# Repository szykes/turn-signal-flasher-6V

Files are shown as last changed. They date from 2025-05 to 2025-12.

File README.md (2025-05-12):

# Turn signal flasher on 6 V for MZ TS 125

This is a template project for old AT90*, ATmega*, and ATtiny* projects. It uses a simple testing and mocking framework and relies on own `avr-libc` version.

## Building firmware
```
cmake -S . -B cmake
```

```
cmake --build cmake --target app
```

## Building and running test
```
cmake -DTEST=True -S . -B cmake-test
```

```
cmake --build cmake-test --target app-test
```

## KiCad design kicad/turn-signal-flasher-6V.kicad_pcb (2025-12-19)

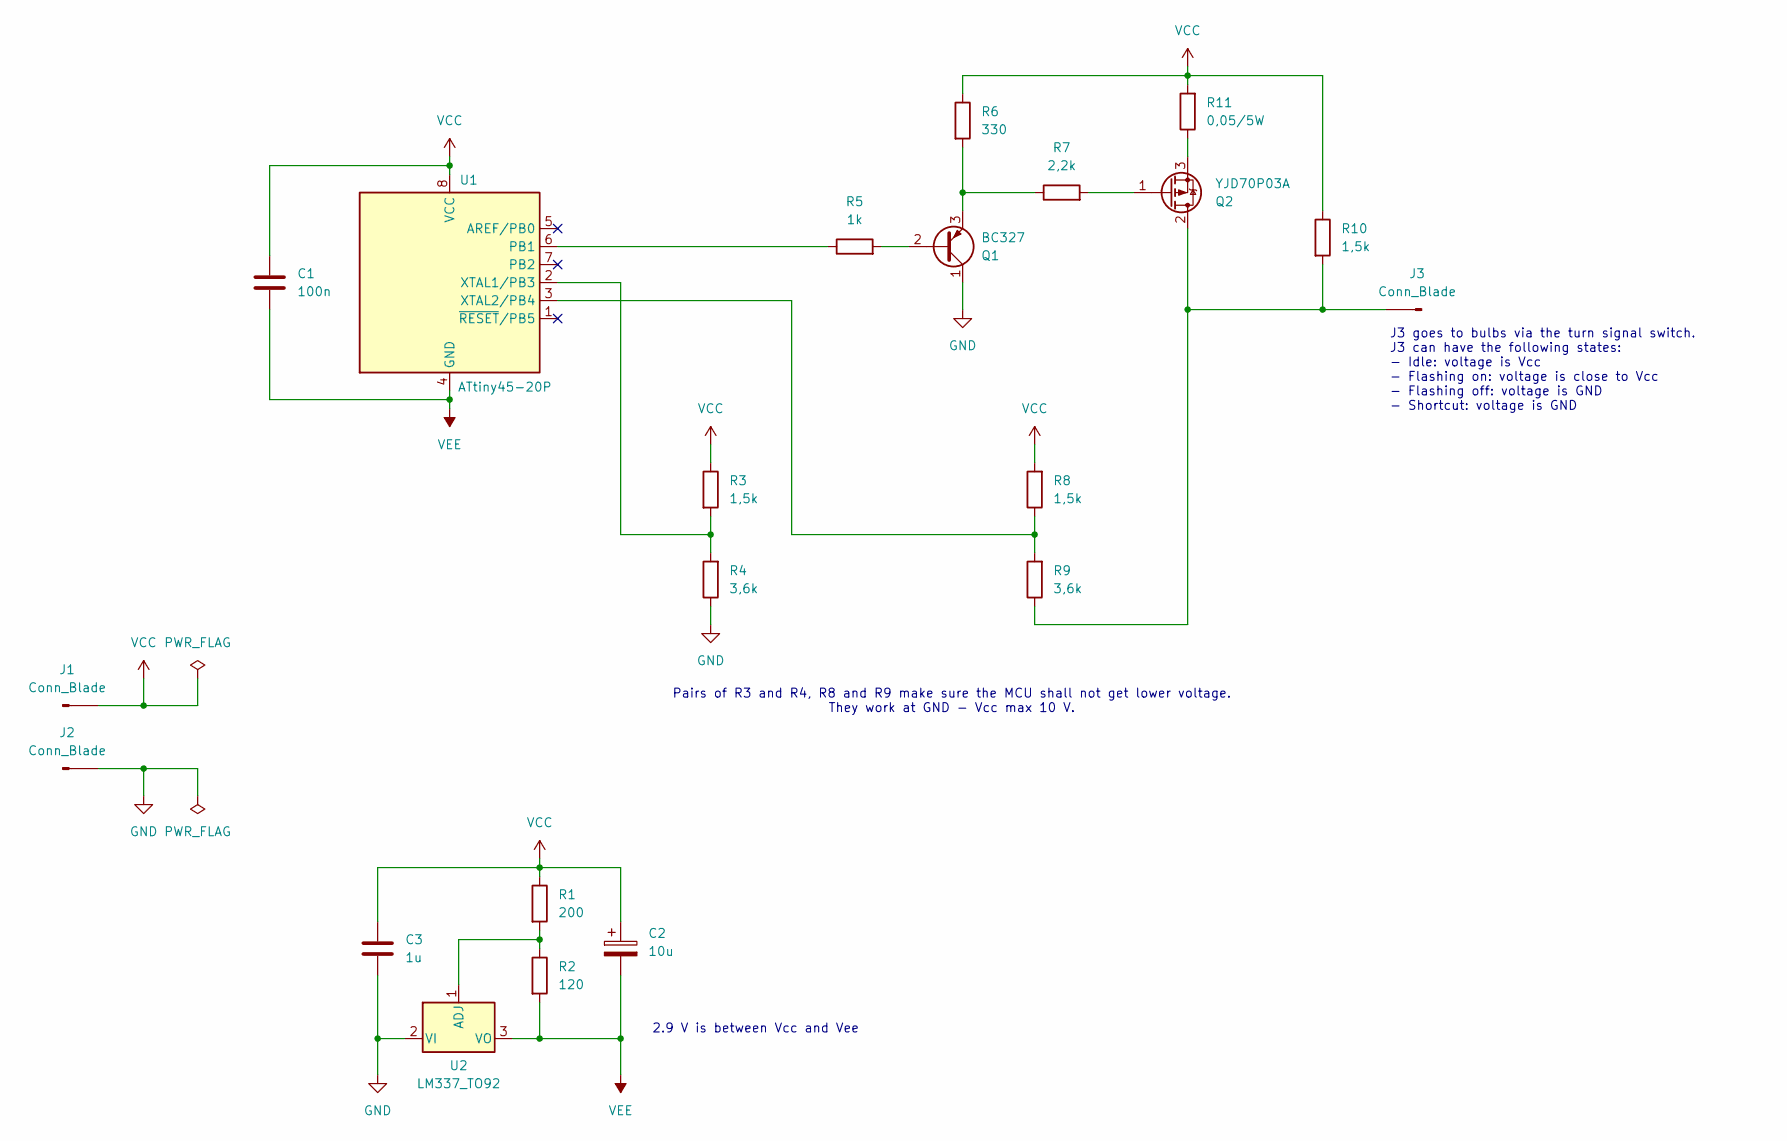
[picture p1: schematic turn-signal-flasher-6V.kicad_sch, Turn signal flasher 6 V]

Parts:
C1: 100n; C_1206_3216Metric_Pad1.33x1.80mm_HandSolder
C2: 10u; CP_Radial_D5.0mm_P2.00mm
C3: 1u; C_1206_3216Metric_Pad1.33x1.80mm_HandSolder
J1, J2, J3: Conn_Blade; BladeConn_6.3x0.8mm_Horizontal
Q1: BC327; TO-92_Inline
Q2: YJD70P03A; TO-252-2
R1: 200; R_1206_3216Metric_Pad1.30x1.75mm_HandSolder
R2: 120; R_1206_3216Metric_Pad1.30x1.75mm_HandSolder
R3, R8, R10: 1,5k; R_1206_3216Metric_Pad1.30x1.75mm_HandSolder
R4, R9: 3,6k; R_1206_3216Metric_Pad1.30x1.75mm_HandSolder
R5: 1k; R_1206_3216Metric_Pad1.30x1.75mm_HandSolder
R6: 330; R_1206_3216Metric_Pad1.30x1.75mm_HandSolder
R7: 2,2k; R_1206_3216Metric_Pad1.30x1.75mm_HandSolder
R11: 0,05/5W; R_Axial_DIN0617_L17.0mm_D6.0mm_P20.32mm_Horizontal
U1: ATtiny45-20P; DIP-8_W7.62mm
U2: LM337_TO92; TO-92

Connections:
GND: C3.2, J2.1, Q1.1 (C), R4.1, U2.2 (VI)
unnamed: J3.1, Q2.2 (D), R9.1, R10.2
unnamed: Q1.2 (B), R5.2
unnamed: Q1.3 (E), R6.2, R7.1
unnamed: Q2.1 (G), R7.2
unnamed: Q2.3 (S), R11.1
unnamed: R5.1, U1.6 (PB1)
unnamed: R3.2, R4.2, U1.2 (XTAL1/PB3)
unnamed: R8.1, R9.2, U1.3 (XTAL2/PB4)
unnamed: R1.2, R2.1, U2.1 (ADJ)
VCC: C1.1, C2.1, C3.1, J1.1, R1.1, R3.1, R6.1, R8.2, R10.1, R11.2, U1.8 (VCC)
VEE: C1.2, C2.2, R2.2, U1.4 (GND), U2.3 (VO)

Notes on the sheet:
Pairs of R3 and R4, R8 and R9 make sure the MCU shall not get lower voltage. They work at GND - Vcc max 10 V.
2.9 V is between Vcc and Vee
J3 goes to bulbs via the turn signal switch. J3 can have the following states: - Idle: voltage is Vcc - Flashing on: voltage is close to Vcc - Flashing off: voltage is GND - Shortcut: voltage is GND

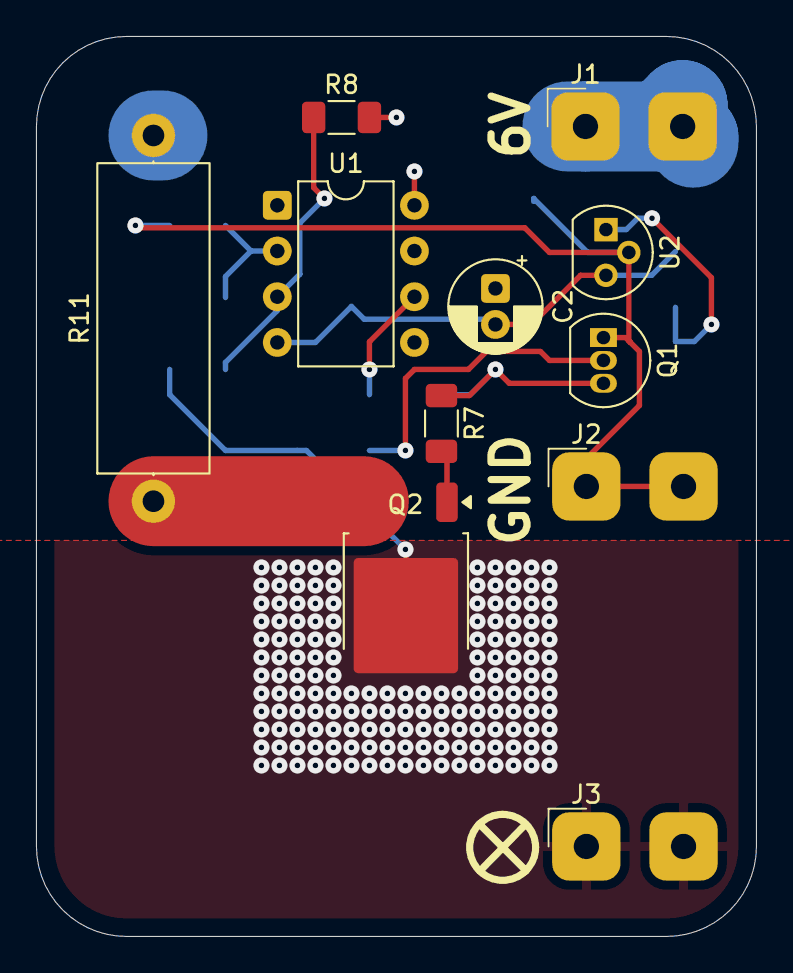
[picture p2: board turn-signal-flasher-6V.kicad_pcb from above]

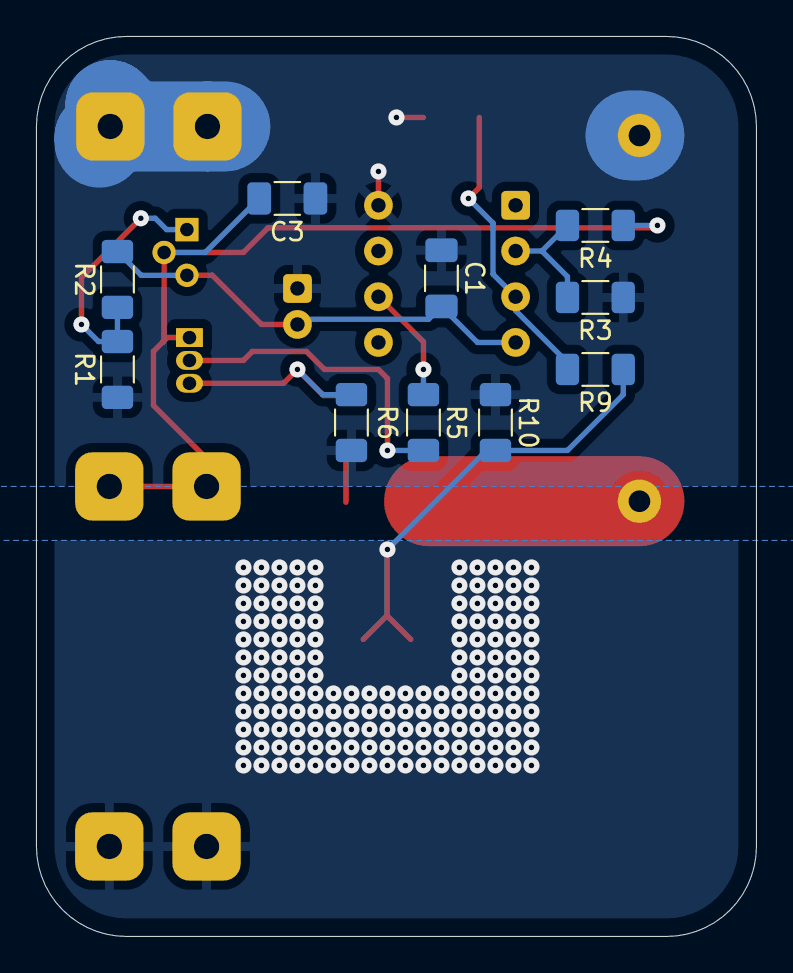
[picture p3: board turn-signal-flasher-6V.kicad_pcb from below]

Board: 2 copper layers, 40.0 x 50.0 mm, 21 parts (10 on the bottom side), 12 nets.

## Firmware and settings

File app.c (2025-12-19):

#include "app.h"

#include "avr.h"

#include <stdbool.h>

#define VOLTAGE_DIFF (15u) // ~170 mV

static volatile bool is_interrupted = false;

static bool is_flashing = false;
static bool is_shortcut = false;

static void evaluate_low_voltage(void) {
  if (gpio_flashing_get_state()) {
    // shortcut
    gpio_flashing_turn_off();
    is_flashing = false;
    is_shortcut = true;
  } else {
    // started flashing OR turned off bulbs OR shortcut
    if (!is_shortcut) {
      is_flashing = true;
    }
  }
}

static void evaluate_high_voltage(void) {
  if (gpio_flashing_get_state()) {
    // turned on bulbs
    // do nothing
  } else {
    // not switched turn signaling
    is_flashing = false;
    is_shortcut = false;
  }
}

static void check_voltage(void) {
  uint8_t voltage = adc_start_and_get();

  if (voltage < VOLTAGE_DIFF) {
    evaluate_low_voltage();
  } else {
    evaluate_high_voltage();
  }
}

static void evaluate_flashing_state(void) {
  static bool prev_is_flashing = false;

  if (!prev_is_flashing && is_flashing) {
    gpio_flashing_turn_on();
    timer_start_long();
  } if (prev_is_flashing && !is_flashing) {
    gpio_flashing_turn_off();
    timer_stop();
  }

  prev_is_flashing = is_flashing;
}

void app_timer_interrupt(void) {
  is_interrupted = true;
}

void app_main(void) {
  bool has_interrupted = false;
  mcu_disable_global_interrupt();
  if (is_interrupted) {
    is_interrupted = false;
    has_interrupted = true;
  }
  mcu_enable_global_interrupt();

  if (has_interrupted) {
    timer_set_short();
    if (gpio_flashing_get_state()) {
      gpio_flashing_turn_off();
    } else {
      gpio_flashing_turn_on();
    }
  }

  // Wait for closing MOSFET
  delay_us(70);

  check_voltage();
  evaluate_flashing_state();
}

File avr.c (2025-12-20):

#include "avr.h"

#include <avr/io.h>
#include <avr/interrupt.h>
#include <avr/wdt.h>

#include <util/delay.h>

#include "app.h"

void hw_init(void) {
  // PB1 -> output for flashing
  // PB3 -> ADC3 -> bulb reference
  // PB4 -> ADC2 -> Vcc reference

  DDRB = (1 << DDB1);
  gpio_flashing_turn_off();

  TIMSK = (1 << OCIE1A);

  ADMUX = (1 << ADLAR) | (1 << MUX1) | (1 << MUX2);
  DIDR0 = (1 << ADC2D ) | (1 << ADC3D);

  wdt_enable(WDTO_250MS);
}

void mcu_enable_global_interrupt(void) {
  sei();
}

void mcu_disable_global_interrupt(void) {
  cli();
}

void delay_us(uint16_t us) {
  _delay_us(us);
}

bool gpio_flashing_get_state(void) {
  return !(PORTB & (1 << PORT1));
}

void gpio_flashing_turn_off(void) {
  PORTB |= (1 << PORT1);
}

void gpio_flashing_turn_on(void) {
  PORTB &= ~(1 << PORT1);
}

void timer_start_long(void) {
  OCR1C = 80; // ~0.65 s
  TCCR1 = (1 << CTC1) | (1 << CS13) | (1 << CS12) | (1 << CS11); // Prescaler is 8192
}

void timer_set_short(void) {
  OCR1C = 55; // ~0.45 s
}

void timer_stop(void) {
  TCCR1 = 0;
  TCNT1 = 0;
}

ISR(TIMER1_COMPA_vect, ISR_BLOCK) {
  app_timer_interrupt();
}

uint8_t adc_start_and_get(void) {
  // ADC = ((Vpos - Vneg) * 1024) / Vcc
  // Vpos -> PB4
  // Vneg -> PB3
  // Conversion runs on 500 kHz, 25 ADC clock cycles are needed -> 50 us
  ADCSRA = (1 << ADEN) | (1 << ADSC);
  while ((ADCSRA & (1 << ADIF)) == 0) {}
  ADCSRA |= (1 << ADIF);
  return ADCH;
}

void wdt_restart(void) {
  wdt_reset();
}

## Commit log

2025-06-19 add kicad-lib submodule
2025-06-22 add init kicad project
    [turn-signal-flasher-6V.kicad_pcb, turn-signal-flasher-6V.kicad_sch]
2025-06-27 add init FW
    [turn-signal-flasher-6V.kicad_sch]
2025-07-24 finalize PCB and code
    [turn-signal-flasher-6V-B_Cu.gbl, turn-signal-flasher-6V-B_Mask.gbs, turn-signal-flasher-6V-B_Silkscreen.gbo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]
2025-12-19 fix: overshoot of MOSFET
    [turn-signal-flasher-6V.kicad_pcb, turn-signal-flasher-6V.kicad_sch]
2025-12-19 fix: first cycle is long, wait before ADC
    [app.c, app_tc.c, avr.c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]
2025-12-20 chore: update schematic svg
